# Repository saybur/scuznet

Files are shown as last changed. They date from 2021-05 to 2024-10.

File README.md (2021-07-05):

scuznet
=======

Open source hardware emulating SCSI hard drives and an Ethernet adapter, for
use with vintage Macintosh computers.

# Status

The firmware is at a beta stage. There are things that are known to not work
correctly, and there are likely a large number of other bugs that have yet to
be identified and/or fixed.

If you encounter problems, please open a new issue.

# Compatibility

This implementation has some limitations by design:

1. There must be only one initiator on the bus.
2. The initiator on the bus must be at ID 7.
3. Read parity is not used. Transmission parity is provided but may be disabled
   to improve performance.

These should not be a significant problem for the target computer platform,
which for the most part has similar limitations.

# License

Except where otherwise noted, all files in this repository are available under
the terms of the GNU General Public License, version 3, available in the
LICENSE document. There is NO WARRANTY, not even for MERCHANTABILITY or
FITNESS FOR A PARTICULAR PURPOSE. For details, refer to the license.

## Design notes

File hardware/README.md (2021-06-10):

scuznet hardware
================

Provided here solely for informational purposes is a prototype hardware design
that was built for testing the scuznet firmware. This is the second revision
of the hardware, which has the following known issues.

* A USB connection is provided but there is (as yet) no hardware support for
  it. I must have lost my mind when selecting this part, it is a PITA to
  solder. Version 2.1 of the board should replace this with something easier
  to work with.
* The power connector footprint is still too big and wiggles around while
  soldering.

This version has not received significant testing yet.

# License

These files are available under the terms of the GNU General Public License,
version 3, available in the LICENSE document in the parent directory. There is
NO WARRANTY, not even for MERCHANTABILITY or FITNESS FOR A PARTICULAR PURPOSE.
For details, refer to the license.

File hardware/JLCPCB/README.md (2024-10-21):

JLCPCB PCB assembly files
=========================

This is a set of files that are useful for JLCPCB PCB Assembly service
They only contain the SMT components, you may have to preorder some components and
will have to do the THT ones by yourself

A few things differs from the main bom:
- USB: this part isn't included as not used
- LEDs: use JLC 8005 basic LEDs (green and yellow)
	- they do need to be run at 1mA otherwise they are too bright
	- R11, R14 and R15 values increased to down to 1mA
- SCSI termination: build for 110Ω packs (R20 = 330Ω, R21 = 422Ω)
- MCU: using ATXMEGA128A3U because stock availability you can use ATXMEGA192A3U
- Power: Uses SS34 instead of SS23, because cheaper and more powerful

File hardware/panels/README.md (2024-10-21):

scuznet panels
==============

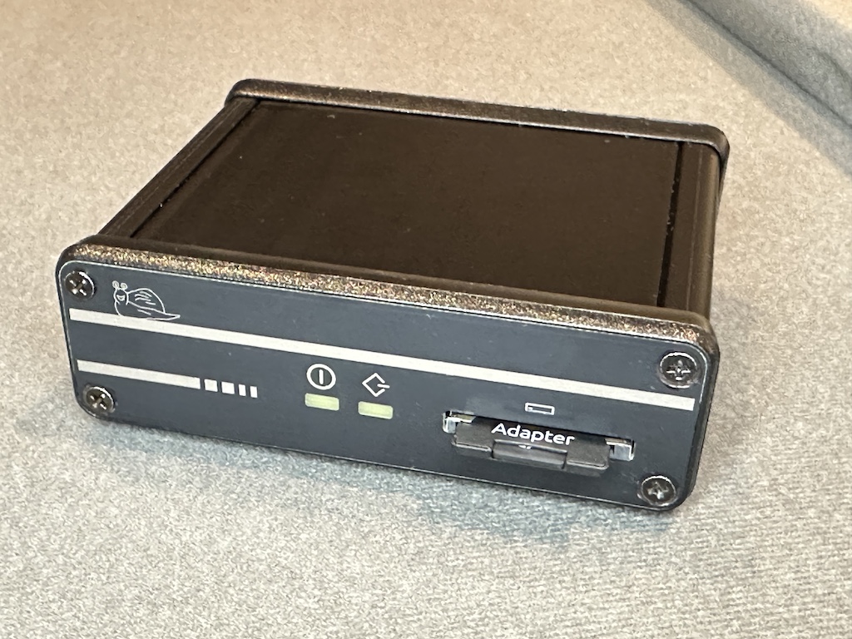
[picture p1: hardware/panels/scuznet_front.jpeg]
An assembled black aluminium case with matching panels


This is a set of FR4 (PCB) panels for the Hammond 1455L801 case. They are designed
to replace the blank panels that come with it

This case is available in a few colors (black anodized pictured above):
- clear anodized aluminium: 1455L801
- black anodized aluminium: 1455L801BK
- blue anodized aluminium: 1455L801BU
- red anodized aluminium: 1455L801RD

For more details, check out the thread
[here](https://68kmla.org/bb/index.php?threads/scsi-to-ethernet-adapter-on-new-hardware.34586/post-546544)
and related context.

Notes
-----
If using JLC to build panels, set "Mark ON PCB" option to "Order Number (Specify Position)"

You will need to do some machining so the panels screws heads can be flush.
You can create a countersink by using by using a big metal drill bit with a cordless drill.
Two turns should be enough, then blackout the visible material with paint or a sharpie

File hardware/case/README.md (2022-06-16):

scuznet case
============

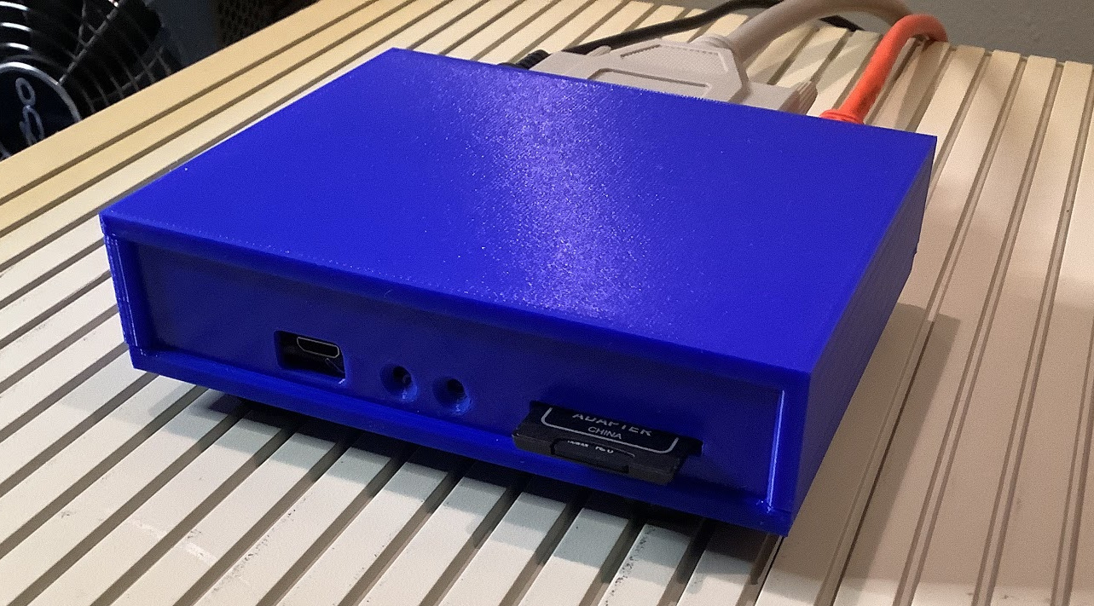
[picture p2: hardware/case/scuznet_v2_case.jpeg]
An assembled case in blue PLA on top of a Mac


This is an awesome 3D printable case for a V2 scuznet, designed by Chopsticks
on 68KMLA and provided graciously to the project. The original post where this
was discussed was lost in the forum crash, but for some details, check out the
thread
[here](https://68kmla.org/bb/index.php?threads/scsi-to-ethernet-adapter-on-new-hardware.34586/page-14#post-444259)
and related context.

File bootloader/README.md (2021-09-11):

scuznet bootloader
==================

A bootloader for scuznet, based on
[mcxboot](https://www.github.com/saybur/mcxboot). Refer to that page for usage
instructions.

**This is only for version 2 boards. This will not work on earlier revisions.**

Before compiling, check the `Makefile` and ensure settings are correct for your
microcontroller revision and programmer.

License
-------

Except where otherwise noted, all files in this repository are available under
the terms of the GNU General Public License, version 3, available in the
LICENSE document. There is NO WARRANTY, not even for MERCHANTABILITY or
FITNESS FOR A PARTICULAR PURPOSE. For details, refer to the license.

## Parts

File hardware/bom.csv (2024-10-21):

refs | # | description | part | digikey | lcsc | notes
C1 | 1 | 100uF Cap | Nichicon UPV1A101MGD | 493-17682-ND
C2-7 | 6 | 10uF Cap | Samsung Electro-Mechanics CL21B106KOQNNNE | 1276-2872-1-ND | C15850
C10-32 | 22 | 100nF Cap | Samsung Electro-Mechanics CL10B104KB8SFNC | 1276-1936-1-ND | C14663 | [1]
C40,41 | 2 | 27pF Cap | AVX Corporation 06035A270FAT2A | 478-10305-1-ND | C107045
D1 | 1 | Protection Diode | ON Semiconductor SS23 | SS23CT-ND | C8678
D2-3 | 2 | Status LED | OSRAM Opto Semiconductors LG R971-KN-1 | 475-1410-1-ND | C2297
D4 | 1 | Error LED | OSRAM Opto Semiconductors LY R976-PS-36 | 475-2560-1-ND | C2296
D5 | 1 | USB Protection | Littelfuse Inc. SP0502BAHTG | F2714CT-ND | C207261 | [4]
F1 | 1 | 1.25A Fuse | Bel Fuse Inc. C1Q 1.25 | 507-1078-1-ND | C3166702
J1 | 1 | DB25 Connector | Amphenol ICC (FCI) D25S13A4GV00LF | 609-1507-ND | -
J2 | 1 | Power Connector | CUI Inc. PJ-037A | CP-037A-ND | C3095627
J3 | 1 | Ethernet Connector | Amphenol RJMG1BD3B8K1ANR | RJMG1BD3B8K1ANR-ND | C5119251
J4 | 1 | SD Holder | Kyocera 145638009211859+ | 478-4059-1-ND | - | [5]
J5 | 1 | PDI Connector | Samtec Inc. TSW-103-07-F-D | SAM10846-ND | C3332728
J6 | 1 | USB Connector | Wurth Elektronik 629105150521 | 732-5960-1-ND | C2894326 | [4]
L1 | 1 | Ethernet Ferrite | TDK Corporation MPZ1608S471ATA00 | 445-5222-1-ND | C87555
R1-6 | 6 | 10Kohm Resistor | Stackpole Electronics Inc RMCF0603JT10K0 | RMCF0603JT10K0CT-ND | C25804
R7-9 | 3 | 22ohm Resistor | Stackpole Electronics Inc RMCF0603FT22R0 | RMCF0603FT22R0CT-ND | C23345
R10 | 1 | 2.32Kohm Resistor | Stackpole Electronics Inc RNCF0603DTE2K32 | RNCF0603DTE2K32CT-ND | C227770
R11-13 | 3 | 330ohm Resistor | Stackpole Electronics Inc RMCF0603FT330R | RMCF0603FT330RCT-ND | C23138
R14-15,R21 | 3 | 165ohm Resistor | Stackpole Electronics Inc RMCF0603FT165R | RMCF0603FT165RCT-ND | -
R16-19 | 4 | 49.9ohm Resistor | Stackpole Electronics Inc RNCP0603FTD49R9 | RNCP0603FTD49R9CT-ND | C23185
R20 | 1 | 150ohm Resistor | Stackpole Electronics Inc RMCF0603FT150R | RMCF0603FT150RCT-ND | -
R22-37 | 16 | 3.3Kohm Resistor | Stackpole Electronics Inc RMCF0603JT3K30 | RMCF0603JT3K30CT-ND | C22978
RN1,2 | 2 | 100ohm Resistor Pack | Bourns Inc. 4610X-101-101LF | 4610X-1-101LF-ND | C840657 | [2]
TP1,2 | 2 | Test Point | Keystone Electronics 5001 | 36-5001-ND | -
U1 | 1 | Main MCU | Microchip Technology ATXMEGA192A3U-AU | ATXMEGA192A3U-AU-ND | C219081 | [3]
U2-5 | 4 | Line Drivers | Texas Instruments SN74LVTH126DR | 296-8663-1-ND | C2675764
U6 | 1 | Control Line Listener | Texas Instruments SN74LVC14ADRG4 | 296-49911-1-ND | C2864988
U7 | 1 | Data Line Listener | Texas Instruments SN74LVT245BDWR | 296-8651-1-ND | C2675854
U8 | 1 | Ethernet Controller | Microchip Technology ENC28J60-I/SO | ENC28J60-I/SO-ND | C47351
U9 | 1 | 3.3V Regulator | Microchip Technology MCP1826S-3302E/DB | MCP1826S-3302E/DB-ND | C638624
U10 | 1 | Terminator Regulator | Texas Instruments LM1117T-ADJ/NOPB | LM1117T-ADJ/NOPB-ND | C485564
Y1 | 1 | Ethernet Crystal | ECS-250-18-4X-CKM | 50-ECS-250-18-4X-CKM-ND | C2649032
- | 1 | Case | Hammond Manufacturing 1455L801 | HM5856-ND | -
- | 1 | Power Supply | CUI Inc. SWI15-5-N-P5 | 102-4159-ND | -
 | [1] | Part performance is not critical, most 100nF X7R 0605 MLCC caps will be fine.
 | [2] | 100ohm value matches R20/21; if using 110ohm packs, R20=121ohm,R21=154ohm
 | [3] | Can recompile to target any A3U-AU chip.
 | [4] | Optional | not yet implemented.
 | [5] | EOL | Wurth Elektronik 693061010911 possible replacement by cutting bottom tabs.

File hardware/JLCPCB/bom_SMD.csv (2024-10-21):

Designator | Footprint | Quantity | Value | LCSC Part #
C10, C11, C12, C13, C14, C15, C16, C17, C18, C19, C20, C21, C23, C24, C25, C26, C27, C28, C29, C30, C31, C32 | 0603 | 22 | 100nF | C14663
C2, C3, C4, C5, C6, C7 | 0805 | 6 | 10uF | C15850
C40, C41 | 0603 | 2 | 27pF | C107045
D1 | D_SMB | 1 | D | C8678
D2, D3 | 0805 | 3 | LED | C2297
D4 | 0805 | 3 | LED | C2296
F1 | 1206 | 1 | Fuse | C3166702
L1 | 0603 | 1 | Ferrite_Bead | C87555
R1, R2, R3, R4, R5, R6 | 0603 | 6 | 10K | C25804
R10, R11 | 0603 | 1 | 2K32 | C227770
R12, R13, R15, R20 | 0603 | 3 | 330 | C23138
R14 | 0603 | 3 | 1K2 | C22765
R16, R17, R18, R19 | 0603 | 4 | 49.9 | C23185
R21 | 0603 | 1 | 422 | C23052
R22, R23, R24, R25, R26, R27, R28, R29, R30, R31, R32, R33, R34, R35, R36, R37 | 0603 | 16 | 3K3 | C22978
R7, R8, R9 | 0603 | 3 | 22 | C23345
U1 | TQFP-64_14x14mm_P0.8mm | 1 | ATXMEGA64A3U | C98800
U2, U3, U4, U5 | SOIC-14_3.9x8.7mm_P1.27mm | 4 | 74LVTH126 | C2675764
U6 | SOIC-14_3.9x8.7mm_P1.27mm | 1 | 74LVC14 | C2864988
U7 | SOIC-20W_7.5x12.8mm_P1.27mm | 1 | 74LVTH245 | C2675854
U8 | SOIC-28W_7.5x17.9mm_P1.27mm | 1 | ENC28J60-I/SP | C47351
U9 | SOT-223-3_TabPin2 | 1 | MCP1826S | C638624

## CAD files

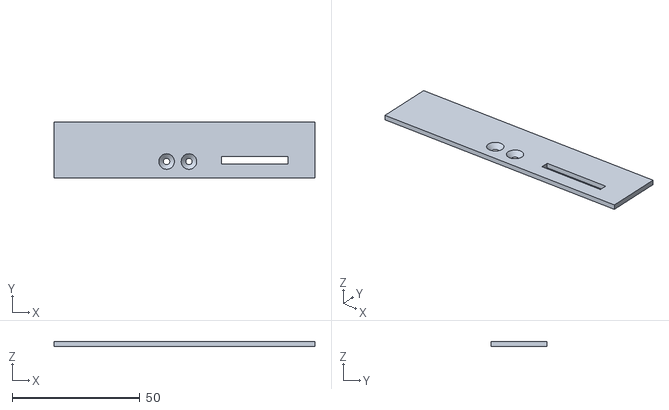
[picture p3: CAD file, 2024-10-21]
hardware/case/Front Panel without USB.stl
102.0 x 22.0 x 1.80

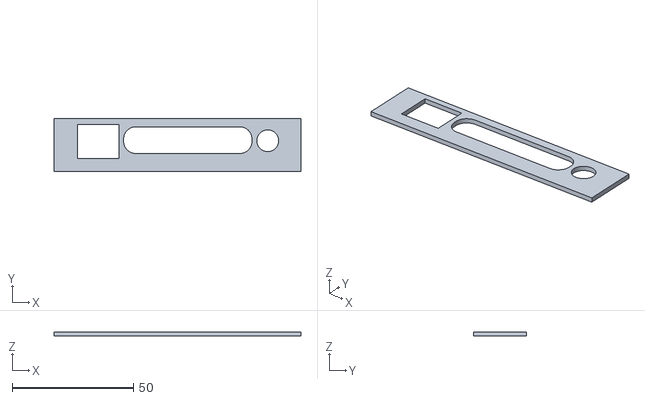
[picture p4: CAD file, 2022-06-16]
hardware/case/Back Panel.stl
102.0 x 22.0 x 1.80

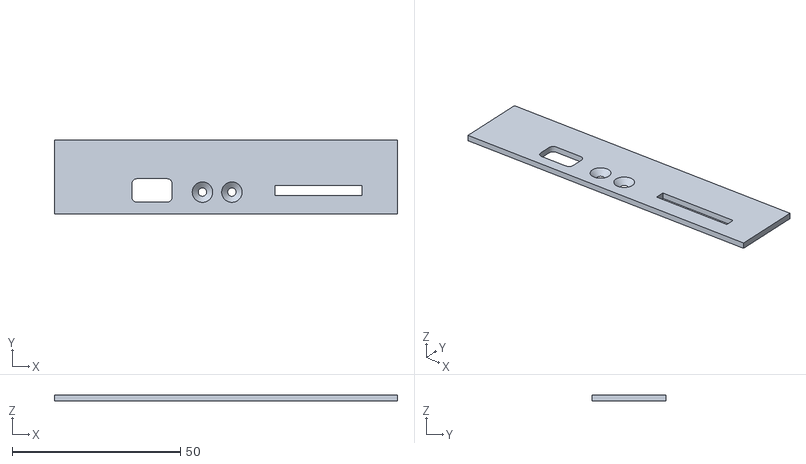
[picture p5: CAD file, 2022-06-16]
hardware/case/Front Panel.stl
102.0 x 22.0 x 1.80

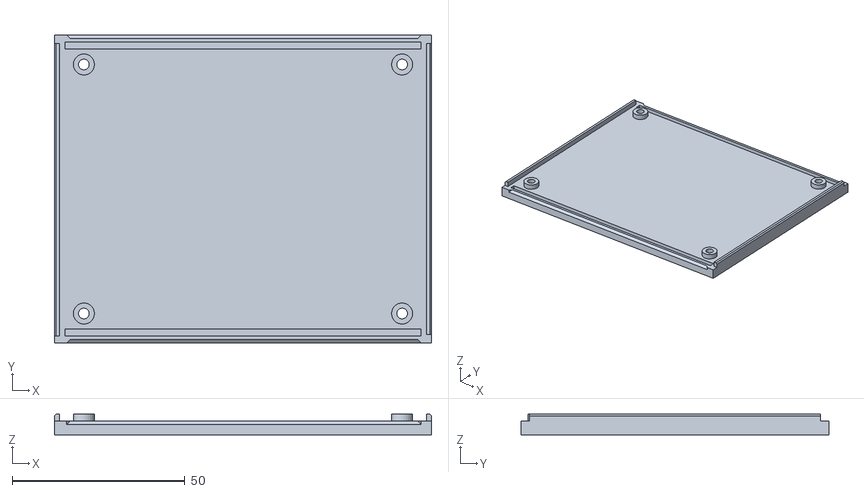
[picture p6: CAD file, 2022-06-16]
hardware/case/Base.stl
109.0 x 89.0 x 6.00

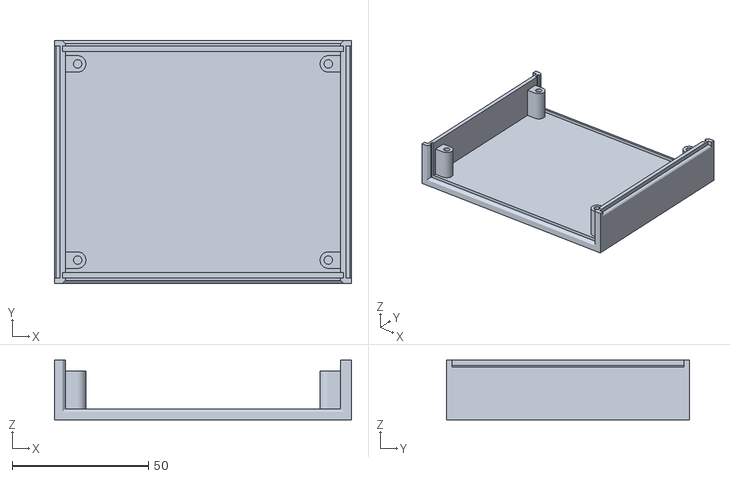
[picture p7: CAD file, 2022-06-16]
hardware/case/Top.stl
109.0 x 89.0 x 22.0

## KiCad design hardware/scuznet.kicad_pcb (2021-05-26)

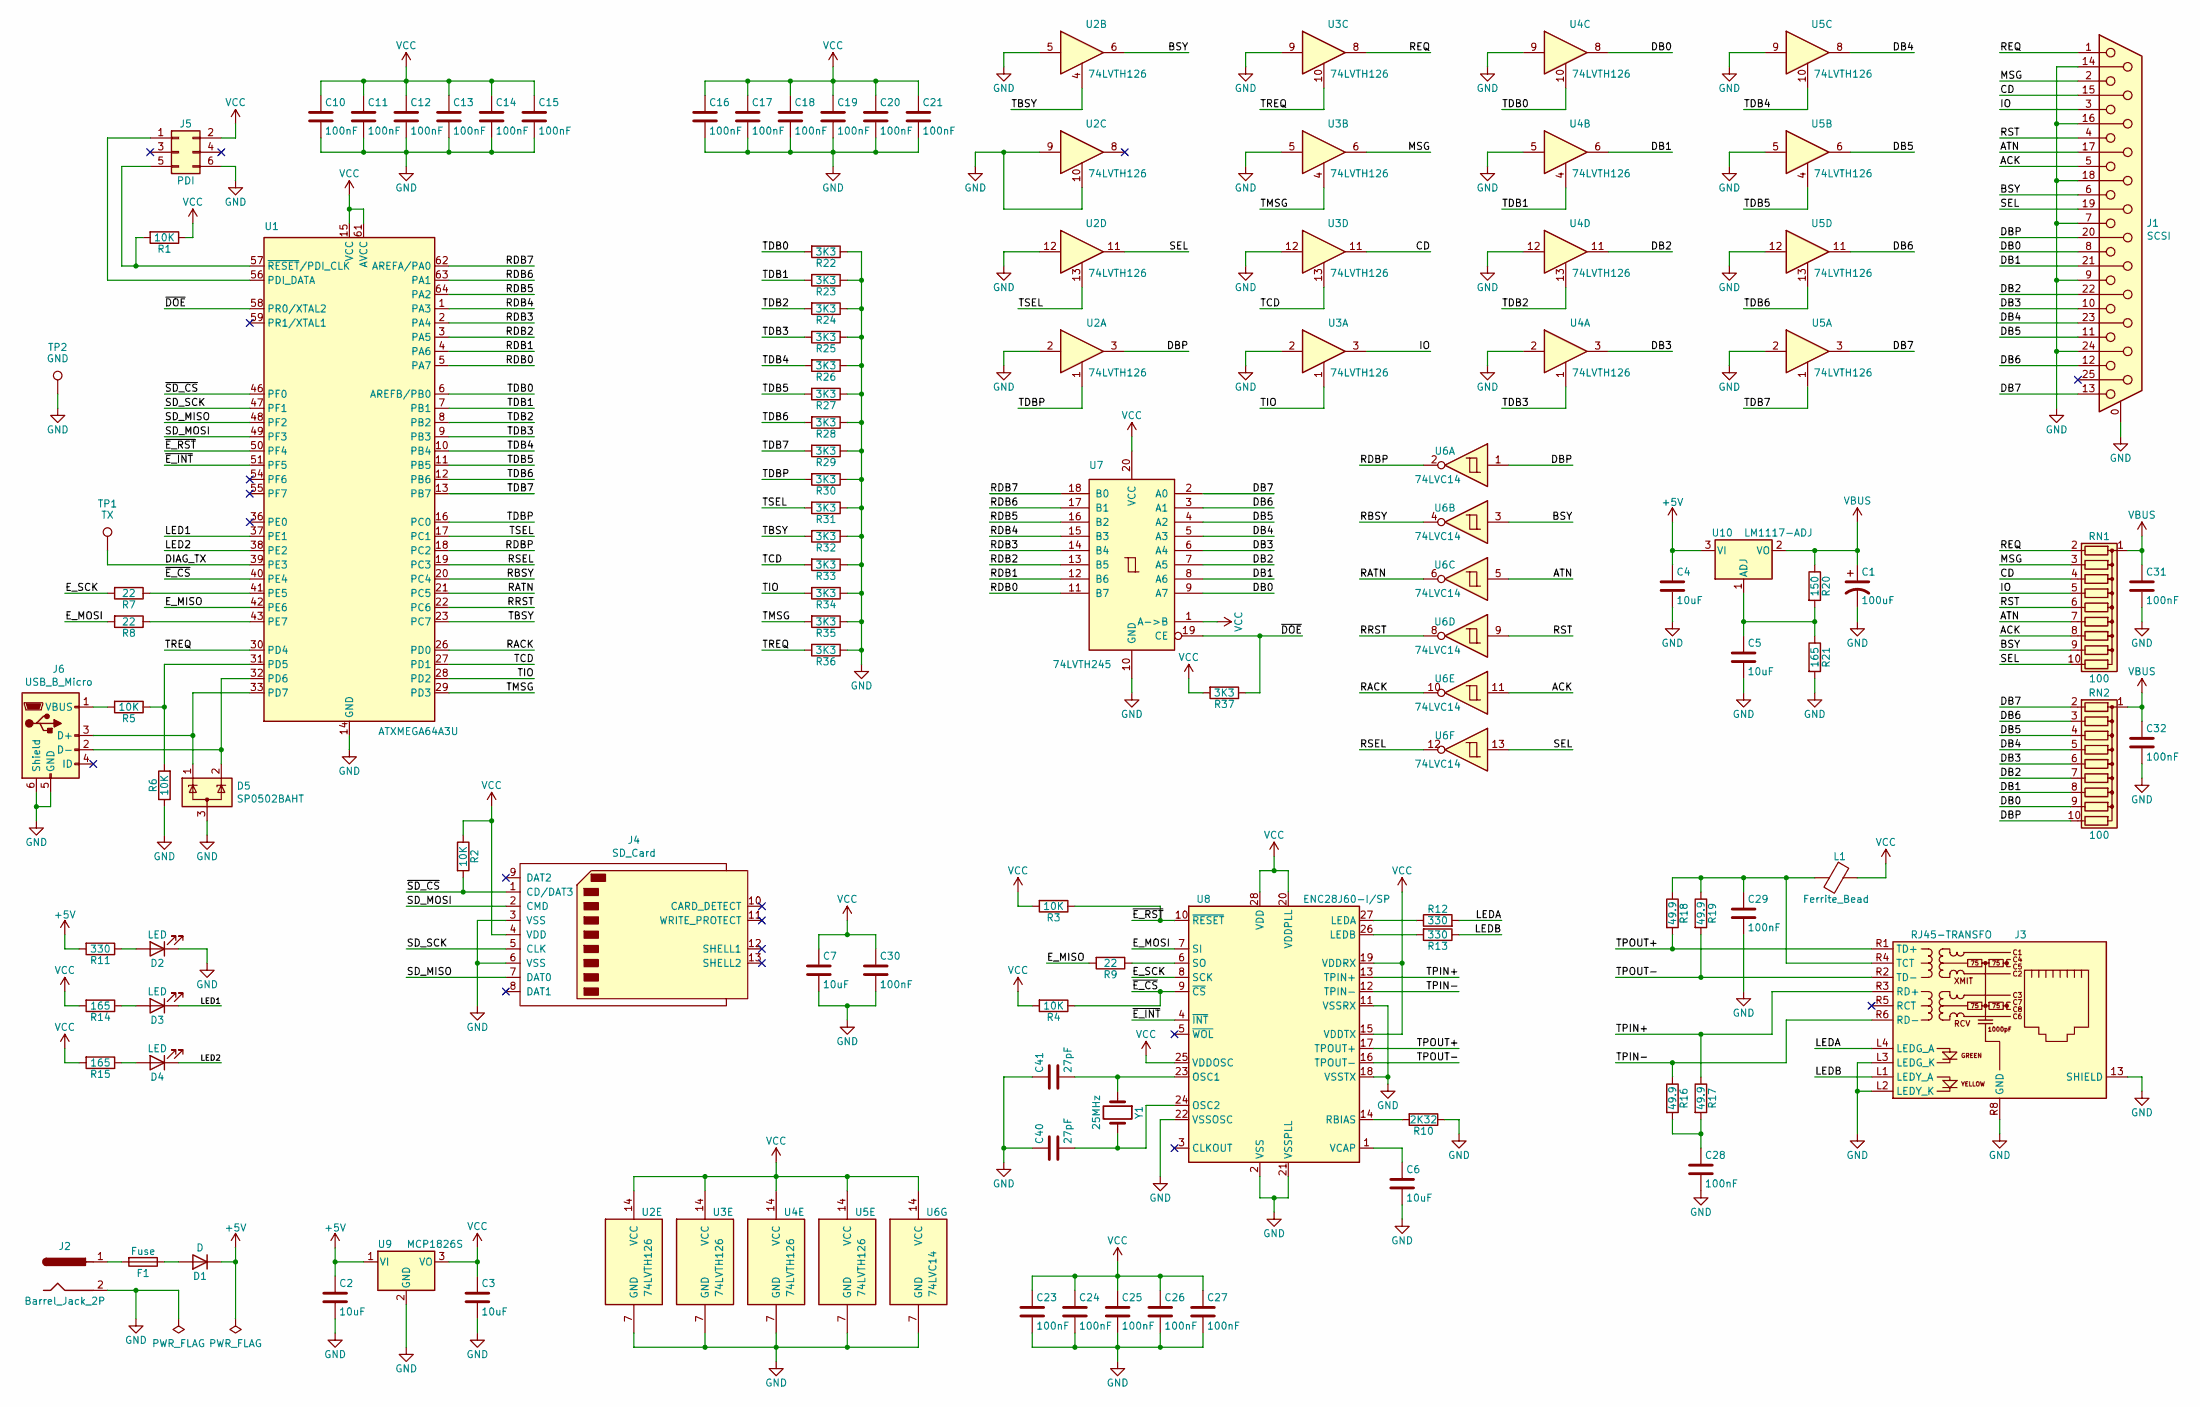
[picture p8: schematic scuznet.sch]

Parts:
C1: 100uF; CP_Radial_D6.3mm_P2.50mm
C2, C3, C4, C5, C6, C7: 10uF; C_0805_2012Metric
C10, C11, C12, C13, C14, C15, C16, C17, C18, C19, C20, C21, C23, C24, C25, C26, C27, C28, C29, C30, C31, C32: 100nF; C_0603_1608Metric
C40, C41: 27pF; C_0603_1608Metric
D1: D; D_SMB
D2, D3, D4: LED; LED_0805_2012Metric
D5: SP0502BAHT; SOT-23
F1: Fuse; Fuse_1206_3216Metric_Pad1.42x1.75mm_HandSolder
J1: SCSI; D25S13A
J2: Barrel_Jack_2P; PJ-037A
J3: RJ45-TRANSFO; RJ45_Amphenol_RJMG1BD3B8K1ANR
J4: SD_Card; SD_Kyocera_145638009211859+
J5: PDI; PinHeader_2x03_P2.54mm_Vertical
J6: USB_B_Micro; USB_Micro-B_Wuerth_629105150521_CircularHoles
L1: Ferrite_Bead; C_0603_1608Metric
R1, R2, R3, R4, R5, R6: 10K; R_0603_1608Metric
R7, R8, R9: 22; R_0603_1608Metric
R10: 2K32; R_0603_1608Metric
R11, R12, R13: 330; R_0603_1608Metric
R14, R15, R21: 165; R_0603_1608Metric
R16, R17, R18, R19: 49.9; R_0603_1608Metric
R20: 150; R_0603_1608Metric
R22, R23, R24, R25, R26, R27, R28, R29, R30, R31, R32, R33, R34, R35, R36, R37: 3K3; R_0603_1608Metric
RN1, RN2: 100; R_Array_SIP10
TP1: TX; TestPoint_Keystone_5000-5004_Miniature
TP2: GND; TestPoint_Keystone_5000-5004_Miniature
U1: ATXMEGA64A3U; TQFP-64_14x14mm_P0.8mm
U2, U3, U4, U5: 74LVTH126; SOIC-14_3.9x8.7mm_P1.27mm
U6: 74LVC14; SOIC-14_3.9x8.7mm_P1.27mm
U7: 74LVTH245; SOIC-20W_7.5x12.8mm_P1.27mm
U8: ENC28J60-I/SP; SOIC-28W_7.5x17.9mm_P1.27mm
U9: MCP1826S; SOT-223-3_TabPin2
U10: LM1117-ADJ; TO-220F-3_Horizontal_TabDown
Y1: 25MHz; Crystal_HC49-4H_Vertical

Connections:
+5V: C2.1, C4.1, D1.1 (K), R11.2, U9.1 (VI), U10.3 (VI)
/ACK: J1.5, RN1.8 (R7), U6.11
/ATN: J1.17, RN1.7 (R6), U6.5
/BSY: J1.6, RN1.9 (R8), U2.6, U6.3
/CD: J1.15, RN1.4 (R3), U3.11
/DB0: J1.8, RN2.9 (R8), U4.8, U7.9 (A7)
/DB1: J1.21, RN2.8 (R7), U4.6, U7.8 (A6)
/DB2: J1.22, RN2.7 (R6), U4.11, U7.7 (A5)
/DB3: J1.10, RN2.6 (R5), U4.3, U7.6 (A4)
/DB4: J1.23, RN2.5 (R4), U5.8, U7.5 (A3)
/DB5: J1.11, RN2.4 (R3), U5.6, U7.4 (A2)
/DB6: J1.12, RN2.3 (R2), U5.11, U7.3 (A1)
/DB7: J1.13, RN2.2 (R1), U5.3, U7.2 (A0)
/DBP: J1.20, RN2.10 (R9), U2.3, U6.1
/DIAG_TX: TP1.1, U1.39 (PE3)
/E_MISO: R9.2, U1.42 (PE6)
/E_MOSI: R8.2, U8.7 (SI)
/E_SCK: R7.2, U8.8 (SCK)
/IO: J1.3, RN1.5 (R4), U3.3
/LED1: D3.1 (K), U1.37 (PE1)
/LED2: D4.1 (K), U1.38 (PE2)
/LEDA: J3.L4 (LEDG_A), R12.2
/LEDB: J3.L1 (LEDY_A), R13.1
/MSG: J1.2, RN1.3 (R2), U3.6
/RACK: U1.26 (PD0), U6.10
/RATN: U1.21 (PC5), U6.6
/RBSY: U1.20 (PC4), U6.4
/RDB0: U1.5 (PA7), U7.11 (B7)
/RDB1: U1.4 (PA6), U7.12 (B6)
/RDB2: U1.3 (PA5), U7.13 (B5)
/RDB3: U1.2 (PA4), U7.14 (B4)
/RDB4: U1.1 (PA3), U7.15 (B3)
/RDB5: U1.64 (PA2), U7.16 (B2)
/RDB6: U1.63 (PA1), U7.17 (B1)
/RDB7: U1.62 (AREFA/PA0), U7.18 (B0)
/RDBP: U1.18 (PC2), U6.2
/REQ: J1.1, RN1.2 (R1), U3.8
/RRST: U1.22 (PC6), U6.8
/RSEL: U1.19 (PC3), U6.12
/RST: J1.4, RN1.6 (R5), U6.9
/SD_MISO: J4.7 (DAT0), U1.48 (PF2)
/SD_MOSI: J4.2 (CMD), U1.49 (PF3)
/SD_SCK: J4.5 (CLK), U1.47 (PF1)
/SEL: J1.19, RN1.10 (R9), U2.11, U6.13
/TBSY: R32.2, U1.23 (PC7), U2.4
/TCD: R33.2, U1.27 (PD1), U3.13
/TDB0: R22.2, U1.6 (AREFB/PB0), U4.10
/TDB1: R23.2, U1.7 (PB1), U4.4
/TDB2: R24.2, U1.8 (PB2), U4.13
/TDB3: R25.2, U1.9 (PB3), U4.1
/TDB4: R26.2, U1.10 (PB4), U5.10
/TDB5: R27.2, U1.11 (PB5), U5.4
/TDB6: R28.2, U1.12 (PB6), U5.13
/TDB7: R29.2, U1.13 (PB7), U5.1
/TDBP: R30.2, U1.16 (PC0), U2.1
/TIO: R34.2, U1.28 (PD2), U3.1
/TMSG: R35.2, U1.29 (PD3), U3.4
/TPIN+: J3.R3 (RD+), R17.1, U8.13 (TPIN+)
/TPIN-: J3.R6 (RD-), R16.1, U8.12 (TPIN-)
/TPOUT+: J3.R1 (TD+), R18.2, U8.17 (TPOUT+)
/TPOUT-: J3.R2 (TD-), R19.2, U8.16 (TPOUT-)
/TREQ: R36.2, U1.30 (PD4), U3.10
/TSEL: R31.2, U1.17 (PC1), U2.13
/~DOE: R37.1, U1.58 (PR0/XTAL2), U7.19 (CE)
/~E_CS: R4.1, U1.40 (PE4), U8.9 (~CS)
/~E_INT: U1.51 (PF5), U8.4 (~INT)
/~E_RST: R3.1, U1.50 (PF4), U8.10 (~RESET)
/~SD_CS: J4.1 (CD/DAT3), R2.2, U1.46 (PF0)
GND: C1.2, C2.2, C3.2, C4.2, C5.2, C6.2, C7.2, C10.2, C11.2, C12.2, C13.2, C14.2, C15.2, C16.2, C17.2, C18.2, C19.2, C20.2, C21.2, C23.2, C24.2, C25.2, C26.2, C27.2, C28.2, C29.2, C30.2, C31.2, C32.2, C40.1, C41.1, D2.1 (K), D5.3 (A), J1.0 (PAD), J1.7, J1.9, J1.14, J1.16, J1.18, J1.24, J2.2, J3.13 (SHIELD), J3.L2 (LEDY_K), J3.L3 (LEDG_K), J3.R8 (GND), J4.3 (VSS), J4.6 (VSS), J5.6, J6.5 (GND), J6.6 (Shield), R6.1, R10.1, R21.2, R22.1, R23.1, R24.1, R25.1, R26.1, R27.1, R28.1, R29.1, R30.1, R31.1, R32.1, R33.1, R34.1, R35.1, R36.1, TP2.1, U1.14 (GND), U1.24 (GND), U1.34 (GND), U1.44 (GND), U1.52 (GND), U1.60 (GND), U2.2, U2.5, U2.7 (GND), U2.9, U2.10, U2.12, U3.2, U3.5, U3.7 (GND), U3.9, U3.12, U4.2, U4.5, U4.7 (GND), U4.9, U4.12, U5.2, U5.5, U5.7 (GND), U5.9, U5.12, U6.7 (GND), U7.10 (GND), U8.2 (VSS), U8.11 (VSSRX), U8.18 (VSSTX), U8.21 (VSSPLL), U8.22 (VSSOSC), U9.2 (GND)
unnamed: C5.1, R20.2, R21.1, U10.1 (ADJ)
unnamed: C6.1, U8.1 (VCAP)
unnamed: C28.1, R16.2, R17.2
unnamed: C29.1, J3.R4 (TCT), L1.2, R18.1, R19.1
unnamed: C40.2, U8.24 (OSC2), Y1.2
unnamed: C41.2, U8.23 (OSC1), Y1.1
unnamed: D1.2 (A), F1.1
unnamed: D2.2 (A), R11.1
unnamed: D3.2 (A), R14.1
unnamed: D4.2 (A), R15.1
unnamed: D5.1 (K), J6.3 (D+), U1.33 (PD7)
unnamed: D5.2 (K), J6.2 (D-), U1.32 (PD6)
unnamed: F1.2, J2.1
unnamed: J5.1, U1.56 (PDI_DATA)
unnamed: J5.5, R1.2, U1.57 (~RESET~/PDI_CLK)
unnamed: J6.1 (VBUS), R5.2
unnamed: R5.1, R6.2, U1.31 (PD5)
unnamed: R7.1, U1.41 (PE5)
unnamed: R8.1, U1.43 (PE7)
unnamed: R9.1, U8.6 (SO)
unnamed: R10.2, U8.14 (RBIAS)
unnamed: R12.1, U8.27 (LEDA)
unnamed: R13.2, U8.26 (LEDB)
VBUS: C1.1, C31.1, C32.1, R20.1, RN1.1 (common), RN2.1 (common), U10.2 (VO)
VCC: C3.1, C7.1, C10.1, C11.1, C12.1, C13.1, C14.1, C15.1, C16.1, C17.1, C18.1, C19.1, C20.1, C21.1, C23.1, C24.1, C25.1, C26.1, C27.1, C30.1, J4.4 (VDD), J5.2, L1.1, R1.1, R2.1, R3.2, R4.2, R14.2, R15.2, R37.2, U1.15 (VCC), U1.25 (VCC), U1.35 (VCC), U1.45 (VCC), U1.53 (VCC), U1.61 (AVCC), U2.14 (VCC), U3.14 (VCC), U4.14 (VCC), U5.14 (VCC), U6.14 (VCC), U7.1 (A->B), U7.20 (VCC), U8.15 (VDDTX), U8.19 (VDDRX), U8.20 (VDDPLL), U8.25 (VDDOSC), U8.28 (VDD), U9.3 (VO)

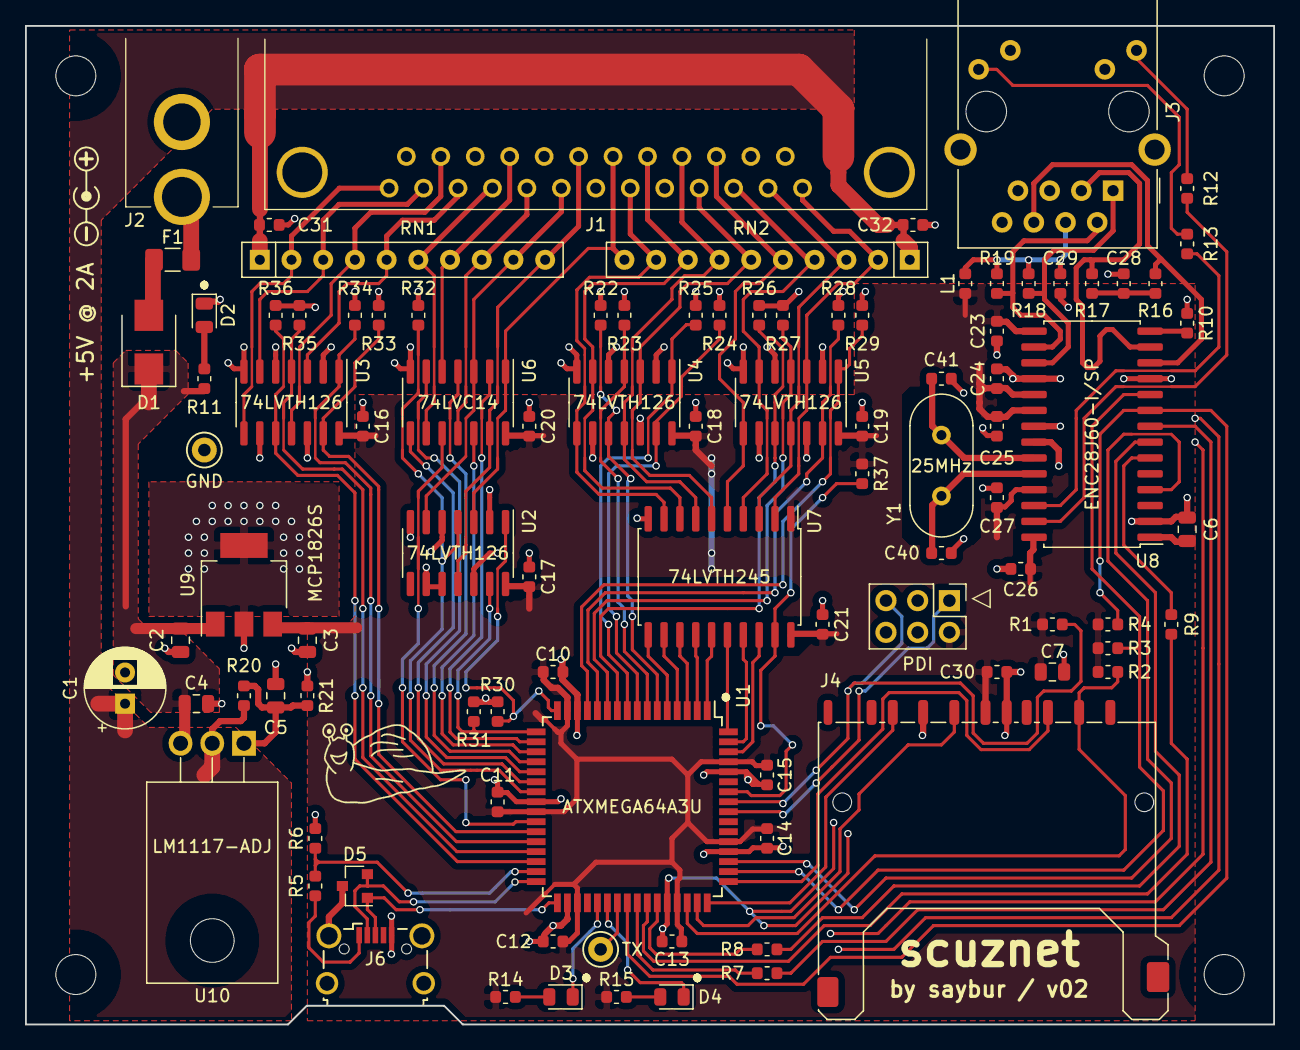
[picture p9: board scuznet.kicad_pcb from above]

Board: 2 copper layers, 100.0 x 80.0 mm, 96 parts (0 on the bottom side), 94 nets.

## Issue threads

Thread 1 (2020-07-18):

Wrong MCU in CSV BOM

ibreakifix, 2020-07-18:
CSV BOM appears to have an incorrect MCU listed (ATXMEGA64A3U) while firmware is for ATXMEGA128A3U

saybur, 2020-08-03:
Fixed to 64A3U in the Makefile, thanks for the report.

Closed 2020-08-03.

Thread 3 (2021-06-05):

>=32GB Cards Fail to Format

saybur, 2021-06-05:
Per report from [superjer2000](https://68kmla.org/forums/topic/58413-scsi-to-ethernet-adapter-on-new-hardware/page/11/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) cards >=32GB were not formatting correctly.

saybur, 2021-06-26:
Switch to FatFs-based card initialization fixed this issue.

Closed 2021-06-26.

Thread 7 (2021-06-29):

MAC address switching at runtime.

saybur, 2021-06-29:
Both the Nuvolink and DaynaPort devices have support for changing the MAC address at runtime. This is not currently implemented.

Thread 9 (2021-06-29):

Nuvolink Stability

saybur, 2021-06-29:
The Nuvolink emulation is unstable on some systems. There seems to be a general correlation between faster systems and more stability, but this is not 1:1. Known trouble spots:

- Emulation is stable on a IIci running system 7.5.5.
- Emulation is stable on a LC running 7.0.1 (at least during initial protocol development, there may have been regressions).
- Emulation is not stable on SE/30s by @superjer2000 and Chopsticks
- Attempting to mount volumes on a SE FDHD running 7.0.1 causes a divide by zero error.

There is a more extensive discussion about this on the 68kmla forum thread. It would be helpful if other users experiencing trouble commented on this issue.

saybur, 2021-07-04:
Significant improvements to Nuvolink stability are on the 'netdev' branch. Stable when tested on my SE, IIsi, and IIci. Needs to be tested on an SE/30, which is the system that most users have reported problems with.

AppleTalk is slow on the SE (only ~8.5KB/s) and there isn't any obvious reason why in Wireshark or on the debugging output. For comparison, I'm getting 125KB/s on the IIsi and 165KB/s on the IIci.

superjer2000, 2021-07-06:
Still freezing on SE/30 - tried with Fetch on system 7.5.3.  Slow ramp up but froze within ~45 seconds of transfer starting with solid light.  Was able to transfer file 6MB with AppleTalk at a reasonable speed (~65kb/s)

saybur, 2021-07-18:
Per forum thread, this should be fixed as of commit 30f6cb3a3b6ea9e641d9e517019c296c0c8c40b4. Will reopen if more problems develop.

Closed 2021-07-18.

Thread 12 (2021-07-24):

Review HDD INQUIRY response.

saybur, 2021-07-24:
The INQUIRY response may not be spec-compliant, making mounting on newer systems error-prone.

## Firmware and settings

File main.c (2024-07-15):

/*
 * Copyright (C) 2019 saybur
 * 
 * This file is part of scuznet.
 * 
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
 * You should have received a copy of the GNU General Public License
 * along with scuznet.  If not, see <https://www.gnu.org/licenses/>.
 */

#include <stdlib.h>
#include <avr/io.h>
#include <util/delay.h>
#include "lib/ff/ff.h"
#include "config.h"
#include "debug.h"
#include "enc.h"
#include "init.h"
#include "hdd.h"
#include "link.h"
#include "logic.h"
#include "net.h"
#include "phy.h"
#include "test.h"

static FATFS fs;
static uint8_t exec_count = 0;
static uint16_t stack_unused = 0xFFFF;

static void main_handle(void)
{
	if (logic_ready())
	{
		uint8_t searching = 1;

		led_on();
		uint8_t target = phy_get_target();
		if (target == config_enet.mask)
		{
			searching = 0;
			if (! link_main())
			{
				searching = 1;
			}
		}
		for (uint8_t i = 0; i < HARD_DRIVE_COUNT && searching; i++)
		{
			if (target == config_hdd[i].mask)
			{
				searching = 0;
				if (! hdd_main(i))
				{
					searching = 1;
				}
			}
		}

		if (searching)
		{
			debug_dual(DEBUG_MAIN_ACTIVE_NO_TARGET, phy_get_target());
			logic_done();
		}

		led_off();
	}
	else if (exec_count == 0)
	{
		uint16_t stackp = debug_stack_unused();
		if (stackp < 4)
		{
			fatal(FATAL_GENERAL, FATAL_STACK_CORRUPTED);
		}
		else if (stackp < stack_unused)
		{
			stack_unused = stackp;
			if (debug_verbose())
			{
				debug(DEBUG_MAIN_STACK_UNUSED);
				debug_dual(stackp >> 8, stackp);
			}
		}
	}

	link_check_rx();
	net_transmit_check();
	hdd_contiguous_check();
	exec_count++;
}

int main(void)
{
	// configure basic peripherals and get ISRs going
	init_mcu();
	init_clock();
	debug_init();
	led_on();
	init_dma();
	enc_init();
	init_mem();
	init_isr();
	debug(DEBUG_MAIN_RESET);

	// fail here if there was a brown-out, so we can easily tell if the
	// PSU is having problems
	uint8_t rst_stat = RST.STATUS;
	RST.STATUS = 0xFF; // clear all flags for next reboot (?)
	if (rst_stat & RST_BORF_bm)
	{
		fatal(FATAL_GENERAL, FATAL_BROWNOUT);
	}

	// mount the memory card
	uint8_t res = f_mount(&fs, "", 0);
	if (res)
	{
		fatal(FATAL_MEM_MOUNT_FAILED, res);
	}

	// read the main configuration file off the card
	uint8_t target_masks;
	config_read(&target_masks);

	// if we're executing a self-test, branch off the usual startup here
	if (GLOBAL_CONFIG_REGISTER & GLOBAL_FLAG_SELFTEST)
	{
		test_check();
		// the above call should never return, but in case it does
		// we should prevent further program execution
		while (1) {};
		return 0;
	}

	// complete setup
	phy_init(target_masks);
	if (config_enet.id != 255)
	{
		// only enable networking if asked
		net_setup(config_enet.mac);
		link_init();
	}
	uint16_t hdd_init_res = hdd_init();
	if (hdd_init_res)
	{
		fatal(hdd_init_res >> 8, hdd_init_res);
	}
	phy_init_hold();
	
	led_off();

	// and continue main handler function
	debug(DEBUG_MAIN_READY);
	while (1)
	{
		main_handle();
	}
	return 0;
}

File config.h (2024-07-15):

/*
 * Copyright (C) 2019 saybur
 * 
 * This file is part of scuznet.
 * 
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
 * You should have received a copy of the GNU General Public License
 * along with scuznet.  If not, see <https://www.gnu.org/licenses/>.
 */

#ifndef CONFIG_H
#define CONFIG_H

#include <avr/io.h>
#include "lib/ff/ff.h"
#if defined(HW_V01)
	#include "hw_v01.h"
#elif defined(HW_V02)
	#include "hw_v02.h"
#else
	#error "You must define a hardware revision, like -DHW_V01"
#endif
#include "link.h"

/*
 * This file defines global built-in configuration values and the hardware
 * configuration.
 */

/*
 * ============================================================================
 *   CONFIGURATION VALUES
 * ============================================================================
 * 
 * Declares the configuration information visible to other parts of the
 * program. These should not be changed. To make modifications to the
 * configuration, edit 'scuznet.ini' on the memory card.
 */

/*
 * Defines the GPIO register used to store global device configuration flags.
 */
#define GLOBAL_CONFIG_REGISTER  GPIOR1

/*
 * Default value, and the location of status flags within the global
 * configuration register.
 */
#define GLOBAL_FLAG_PARITY               _BV(0)
#define GLOBAL_FLAG_DEBUG                _BV(1)
#define GLOBAL_FLAG_VERBOSE              _BV(2)
#define GLOBAL_FLAG_HDD_CHECKING         _BV(3)
#define GLOBAL_FLAG_HDD_CHECKED          _BV(4)
#define GLOBAL_FLAG_SELFTEST             _BV(5)

/*
 * The number of virtual hard drives that can be supported simultaneously.
 * 
 * This will break the debug-flash system if increased beyond 4.
 */
#define HARD_DRIVE_COUNT        4

/*
 * The Ethernet controller configuration information.
 */
typedef struct ENETConfig_t {
	uint8_t id;                 // disabled when set to 255
	uint8_t mask;               // the bitmask for the above ID
	LINKTYPE type;
	uint8_t mac[6];
} ENETConfig;
extern ENETConfig config_enet;

/*
 * The different options to set for the 'mode' value below.
 */
typedef enum {
	HDD_MODE_NORMAL,            // access is always through FAT
	HDD_MODE_FAST,              // low-level access if file contiguous
	HDD_MODE_FORCEFAST          // always low-level access (dangerous!)
} HDDMODE;

/*
 * The virtual hard drive configuration information.
 */
#define HDD_FILENAME_SIZE 13 // 8.3+'\0'
typedef struct HDDConfig_t {
	uint8_t id;                 // disabled when set to 255
	uint8_t mask;               // the bitmask for the above ID
	char filename[HDD_FILENAME_SIZE];
	uint32_t lba;	            // if !=0, start LBA for direct volumes
	uint32_t size;              // size of HDD in sectors
	FIL fp;
	HDDMODE mode;
} HDDConfig;
extern HDDConfig config_hdd[HARD_DRIVE_COUNT];

/*
 * ============================================================================
 *   GLOBAL BUFFER
 * ============================================================================
 * 
 * This is a slice of memory available for the memory card access code, or
 * another part of the program executing when access to the memory card is not
 * being performed.
 */
#define GLOBAL_BUFFER_SIZE      1032 // must be at least 516 * 2
extern uint8_t global_buffer[GLOBAL_BUFFER_SIZE];

/*
 * ============================================================================
 *   HARDWARE CONFIGURATION
 * ============================================================================
 *
 * Different board revisions may have differnet pin assignments, which are
 * defined in separate headers added via an include into this file. A few
 * items get defined here if they are common to all -AU cores that could run
 * this firmware.
 */

/*
 * ****************************************************************************
 *   MEMORY CARD
 * ****************************************************************************
 */

/*
 * Defines how fast to run the SPI subsystem for the memory card when in
 * initialization mode and in standard mode. When initializing, this should be
 * between 100-400kbps. If the main MCU clock is changed this may need to be
 * updated to stay within specs. During normal operations, this should
 * probably be as fast as possible, hence 0.
 * 
 * Note: 39 is 400kbps @ 32MHz
 */
#define MEM_BAUDCTRL_INIT       39
#define MEM_BAUDCTRL_NORMAL     0

/*
 * Timer used to implement timeouts with the memory card inteface.
 */
#define MEM_TIMER               TCF0
#define MEM_TIMER_OVF           TC0_OVFIF_bm

/*
 * DMA 
 */
#define MEM_DMA_READ            DMA.CH0
#define MEM_DMA_WRITE           DMA.CH1
#define MEM_GPIOR               GPIORF

/*
 * ****************************************************************************
 *   ETHERNET PHY / NETWORKING
 * ****************************************************************************
 * 
 * This subsystem requires access to two DMA channels, the peripherals below,
 * additional resources in the hardware definitinos, and the CRC unit for
 * calculating hash filter values.
 */
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

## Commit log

2019-12-11 Initial project commit.
    [scuznet.kicad_pcb, scuznet.sch]
2020-01-23 Missing BOM added
    [bom.csv]
2020-04-12 Experimental support for omitting hardware features on new board revisions.
2020-04-19 Alternate HDD only hardware configuration prototype.
2020-04-19 Broken out clock/debug to support future variable clock rate setting.
    [main.c]
2020-04-23 Removed constant parity enable check, reorganized branches.
    Reads now 822kB/s, up from ~635kB/s. I should really use the DMA unit to properly torpedo this speed bottleneck...
2020-04-25 Replaced block transfer routine with assembly.
    Read performance is now ~950kB/s on my system with this.
    [hw_v01.h]
2020-04-26 Added basic MODE SENSE and associated commands, plus more debug prints.
2020-08-03 Change part to match BOM
2020-10-22 Add blinking fail for brown-out reset
    [main.c]
2020-10-23 Start of post-assembly board testing firmware.
2020-10-24 Fixed pin reference.
2020-10-24 Try to fix fail detect on working board
    [main.c]
2020-10-24 Updated docs (not implemented yet) and added image for test attachment.
2020-10-24 /SEL has its own driver, no connection on that one needed.
2020-10-24 Prototype control line testing code, not verified yet.
2021-05-25 Added EXPERIMENTAL support for hardware version 2.
    Do not use this version on version 2 boards unless you are willing to work around potentially severe bugs.
    [config.h, hw_v02.h]
2021-05-26 Hardware revision 2.
    [scuznet-B_Cu.gbl, scuznet-B_Mask.gbs, scuznet-B_Paste.gbp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]
2021-05-27 Pre-order changes.
    [bom.csv]
2021-06-09 Fixed bugs noticed in the BOM post-assembly of V2 board.
    [bom.csv]
2021-06-13 Never got around to making this hypothetical board.
2021-06-13 No longer optional to include both HDD/Ethernet support.
    This will hopefully streamline the configuration changes coming down the pipeline.
    [hw_v01.h, hw_v02.h]
2021-06-13 Proof of concept for using FatFs with this board.
2021-06-18 Added function prototypes for FatFs and documented intended changes.
2021-06-18 Setup code for DMA and tweaks to the PHY.
2021-06-18 Broken FatFs multi-write support.
    This has a partially implemented multi-write call. This works only for
    files less than about 32K or so, which makes me think the issue is
    probably something to do with cluster boundaries and how the caches switch
    around when you hit them. I haven't been able to figure this out, so I'm
    going to try switching to the much simpler Petit FatFs and trade my
    problems out :)
    [disk.c]
2021-06-18 Back to Petit FatFs. Test board is now working again.
2021-06-19 Snapshot of current work, do not use in the future.
    Things are not working for the multiple writes - any time I activate any part of the new code, it immediately breaks things. Not sure what's malfunctioning.
    [debug.h, disk.c]
2021-06-19 DMA writes now work!
    SCSI Evaluator on my IIci went from ~100KB/s to ~900KB/s, which is nice.
    The "+ cs" on the "sect" variable appears to have been the underlying
    problem.
    [disk.c]
2021-06-20 Non-DMA CMD18 reads working. Speed is ~500KB/s on IIci.
2021-06-20 Multi-block DMA reads now working, yay.
    Getting ~800KB/s across the board on both reads and writes on my IIci.
2021-06-20 Configuration now done via scuznet.ini
    Hard drive sizing to the provided image file is not working yet, still
    fixed at 500MB.
    [config.h, debug.h, main.c]
2021-06-21 Reminder for myself next time I go down a rabbit hole :)
2021-06-23 Fixed case where /SEL still active during check caused unexpected bus release.
    Also fixed bug where hdd_main() check was inverted, oops.
    [main.c]
2021-06-23 The REQUEST SENSE current error code is 0x70, with high bit set for validity.
2021-06-24 Shift from 64A3U to 192A3U as "default" MCU
    [bom.csv]
2021-06-24 Fixed-length transfer functions for the Petit FatFs modifications.
    This probably won't do much for performance now, but later it will help support loop unrolling and other trickery to squeeze more juice out of the SCSI bus.
    [disk.c]
2021-06-26 INQUIRY data into flash memory.
    This switch to __flash instead of PROGMEM is more "modern," and should free up some precious SRAM.
2021-06-27 Tweaks to base ENC filter control.
2021-06-27 Enable/disable reception on the ENC28J60 during filter switch, per 7.2.1
2021-06-27 Broke out command / MAC handler for each device.
2021-06-27 Handle case where link is unable to hang up the bus.
2021-06-27 Moving away from the "one byte pending" USART approach.
    This was making my head hurt. The new approach is slightly slower but should be easier to understand.
    This also leaves the RX part of the USART enabled during write ops. As I recall, this was an issue ages ago when I was experimenting with DMA transactions, which may come back again later.
2021-06-27 Incorporating @superjer2000 contributed Daynaport support.
    Also moved around the _pgm stuff to support more __flash. Things are mostly working, hard-coded to the Dayna device. More work needed.
2021-06-29 Fix major bug with raw volumes and add FAT bypass on some files.
    The bug was using .size instead of .start for LBA offsets, which could easily result in data loss (yikes!)
    Also adds 'mode=fast' option for bypassing the FAT layer on fully contiguous files.
    [config.h]
2021-06-29 Move the HDD memory card scan to config.c
    There will be more added here shortly.
    [config.h]
2021-06-29 Added option for forcing 'fast' mode on without the long check.
    Eventually this will need to be fixed by switching away from hard-resetting the MCU every time /RST goes active.
    [config.h]
2021-06-30 Major, untested, and incomplete changes to networking.
    Move all ENC code over to net.c, and setup for making packet header reading interrupt-driven.
2021-07-02 Current status of work, but thinking of a different tack.
    I'm not sure this is really saving much chip time. Might be better to only store one header, as before, but still use DMA to get that header into the chip? It would put the read pointer at the right 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
2021-07-02 Missed including flag to decrement the packet counter.
    [net.c]
2021-07-03 Fixed issue where packet RX failed when not 1:1 with TX.
    Packet flow with the Nuvolink is now mostly OK. Still some hiccups to sort out.
    [net.c]
2021-07-03 config_read() now directly fails, and added # bytes trailing debug symbols.
    Also added README entries for the fatal flash codes.
    [config.h, debug.h, disk.c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]
2021-07-03 Adding a debug flag during reset.
    [debug.h, main.c]
2021-07-03 Changes to handle stalled transmit packets.
    This has not completely solved the problem.
    [debug.h, net.c]
2021-07-03 Redid how transmission check worked.
    Feels more stable. Did 30MB in 180 seconds, ~167KB/s, which is a significant improvement. It also didn't have any obvious stalls during the transfer.
    [config.h, debug.h, main.c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]
2021-07-04 Fixed implementation error with Nuvo filtering.
2021-07-04 Hardware V2 now uses amber LED for activity, green for power indication.
2021-07-07 Need to leave high interrupts on to allow safe /RST behavior.
2021-07-07 hdd_contiguous_check() reworked.
    'forcefast' was not implemented and the logic was kind of gross.
    [debug.h]
2021-07-08 MTU to 1518 (was previously 1536 per reset value)
    [net.c]
2021-07-09 Extend the reselection delay from ~250us to ~5000us.
    This seems to have significantly increased stability with FTP transfers.
    [config.h]
2021-07-09 Revert "Experimental single-TX buffer instead of dual-TX, for more RX space."
    This reverts commit fca2c02974866f343f72b3476791d5ce3ee4c754.
    Improves performance on test system but may have ripple effects, not going
    to implement right away. If the other fixes help with stability this can be
    revisited.
    [net.c]
2021-07-16 Fix memory card DMA read underflows.
    Before this, if a byte got missed the DMA read channel would never end, stalling the system.
    Now ignored during data writes, where the only byte of interest is the last one anyway and already has a check.
    During data reads underflow triggers a soft error and should now resolve itself.
    [debug.h, disk.c]
2021-07-17 Line was breaking DMA read recoveries.
2021-07-17 Added stack usage detection.
    There is heap usage via the string library, so this will always report 0.
    Will be fixed in a later commit.
    [debug.h, main.c]
2021-07-17 Fixed suspected race condition with the net DMA system.
    [net.c]
2021-07-17 Prevent race condition during DMA unit startup.
    [disk.c]
2021-07-18 Work around Dayna driver issues with short packet turnarounds.
2021-07-18 Brownout is now 7 long / 2 short.
    [debug.h, main.c]
2021-07-18 Filename will never be NULL after switch to stack allocation.
2021-07-18 Simplification of the logic error reporting system.
    This helps hide more of the low-level details and frees some more memory.
    [debug.h]
2021-07-24 Reflect change in BOM to 192A3U
2022-06-16 Added the 3D case Chopsticks designed :)
    [Back Panel.stl, Base.stl, Front Panel.stl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]
2024-08-05 added case Front Panel for builds without USB
    [Front Panel without USB.stl]
2024-10-20 replaced obsolete components where possible, anded LCSC parts numbers
    [bom.csv]
2024-10-20 added JLCPCB PCB assmebly files and notes, and FR4 panels
    [bom_SMD.csv, positions_SMD.csv, scuznet_back.kicad_pcb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]

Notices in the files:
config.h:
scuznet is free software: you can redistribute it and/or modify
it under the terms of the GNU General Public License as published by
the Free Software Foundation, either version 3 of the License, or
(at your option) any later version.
